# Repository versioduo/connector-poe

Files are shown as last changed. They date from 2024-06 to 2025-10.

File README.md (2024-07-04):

# connector-poe

⚡ V2 Link + Power Over Ethernet Mode B 

## Board

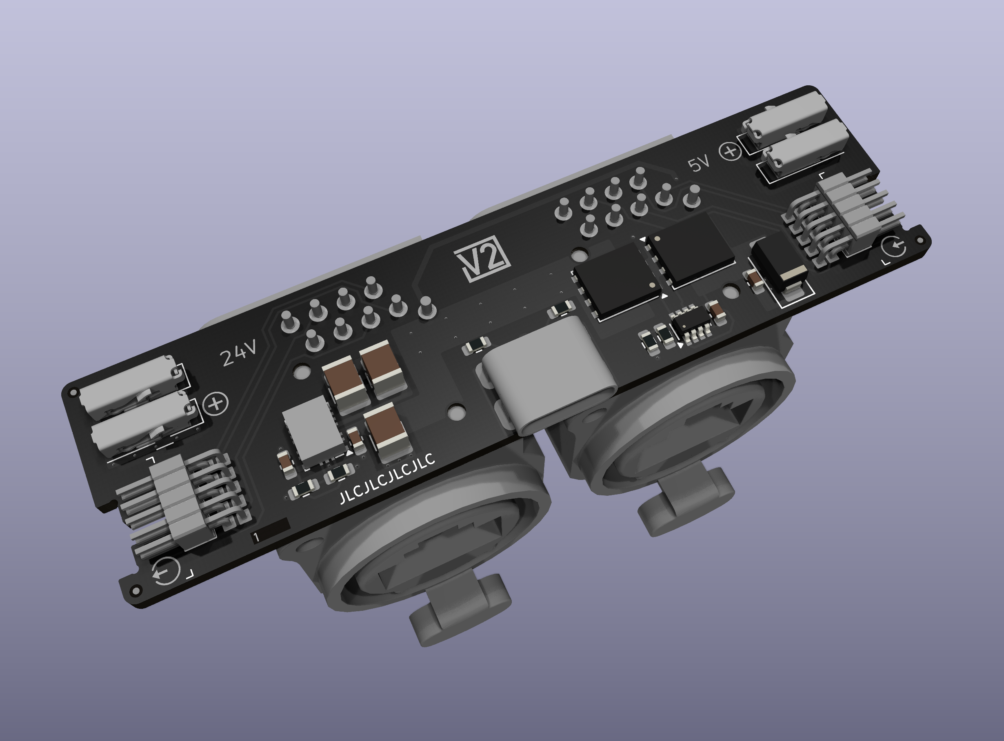
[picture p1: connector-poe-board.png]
board


## Schematic

[PDF](connector-poe.pdf)

## Bill Of Materials

[Interactive BOM](https://htmlpreview.github.io/?https://github.com/versioduo/connector-poe/main/connector-poe-bom.html)

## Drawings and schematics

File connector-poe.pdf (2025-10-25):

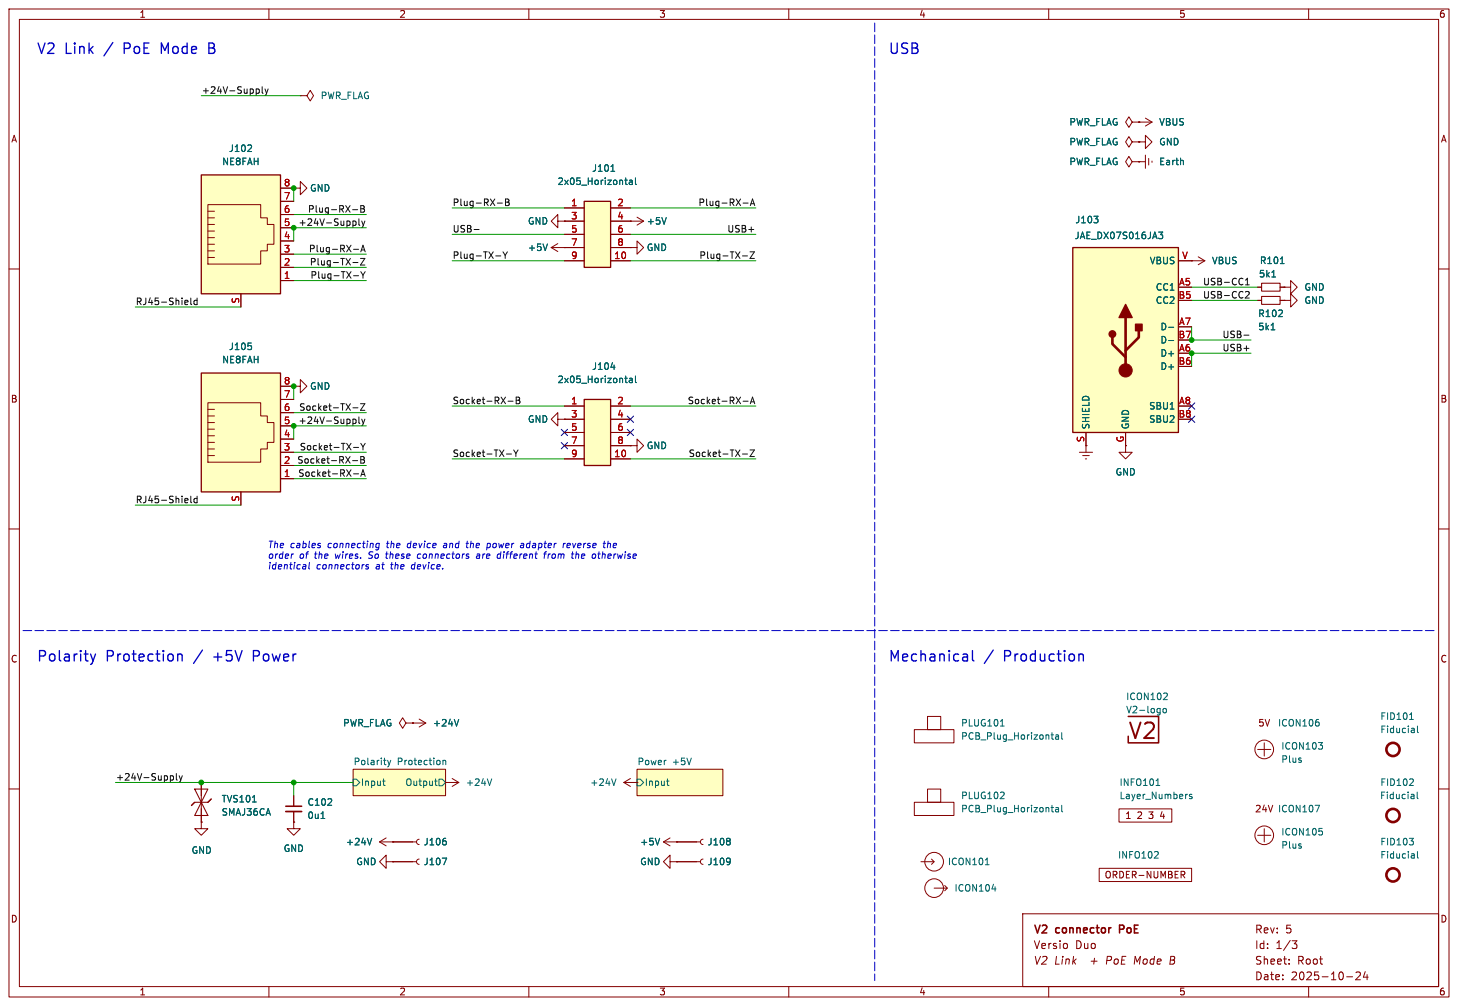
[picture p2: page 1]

Plug-TX-Z Socket-RX-A

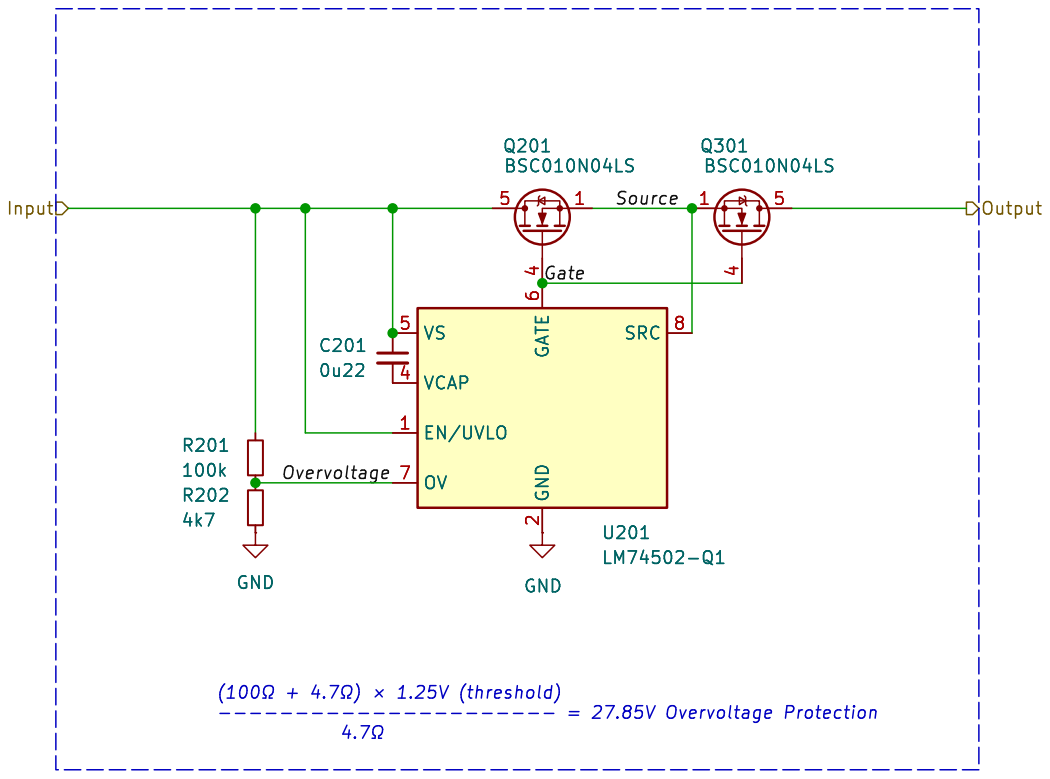
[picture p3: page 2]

þÿ(100©+ þÿ4.7©) þÿ×1.25V (threshold)

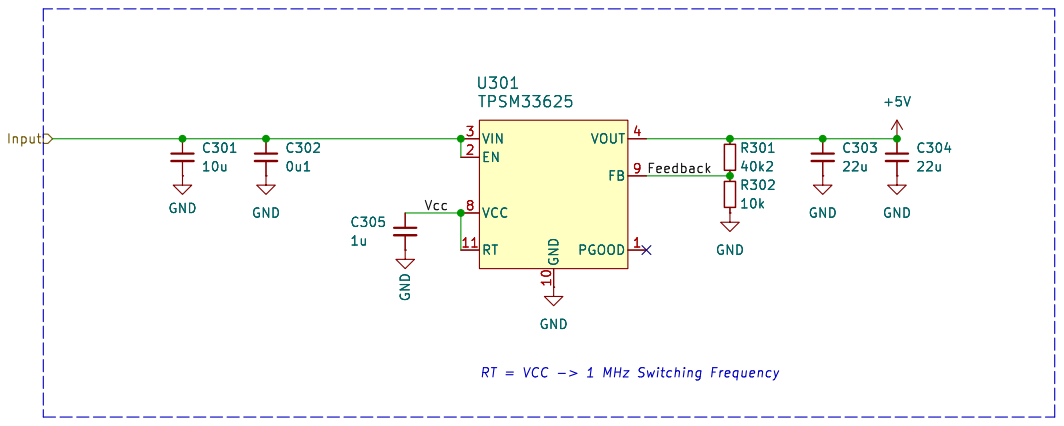
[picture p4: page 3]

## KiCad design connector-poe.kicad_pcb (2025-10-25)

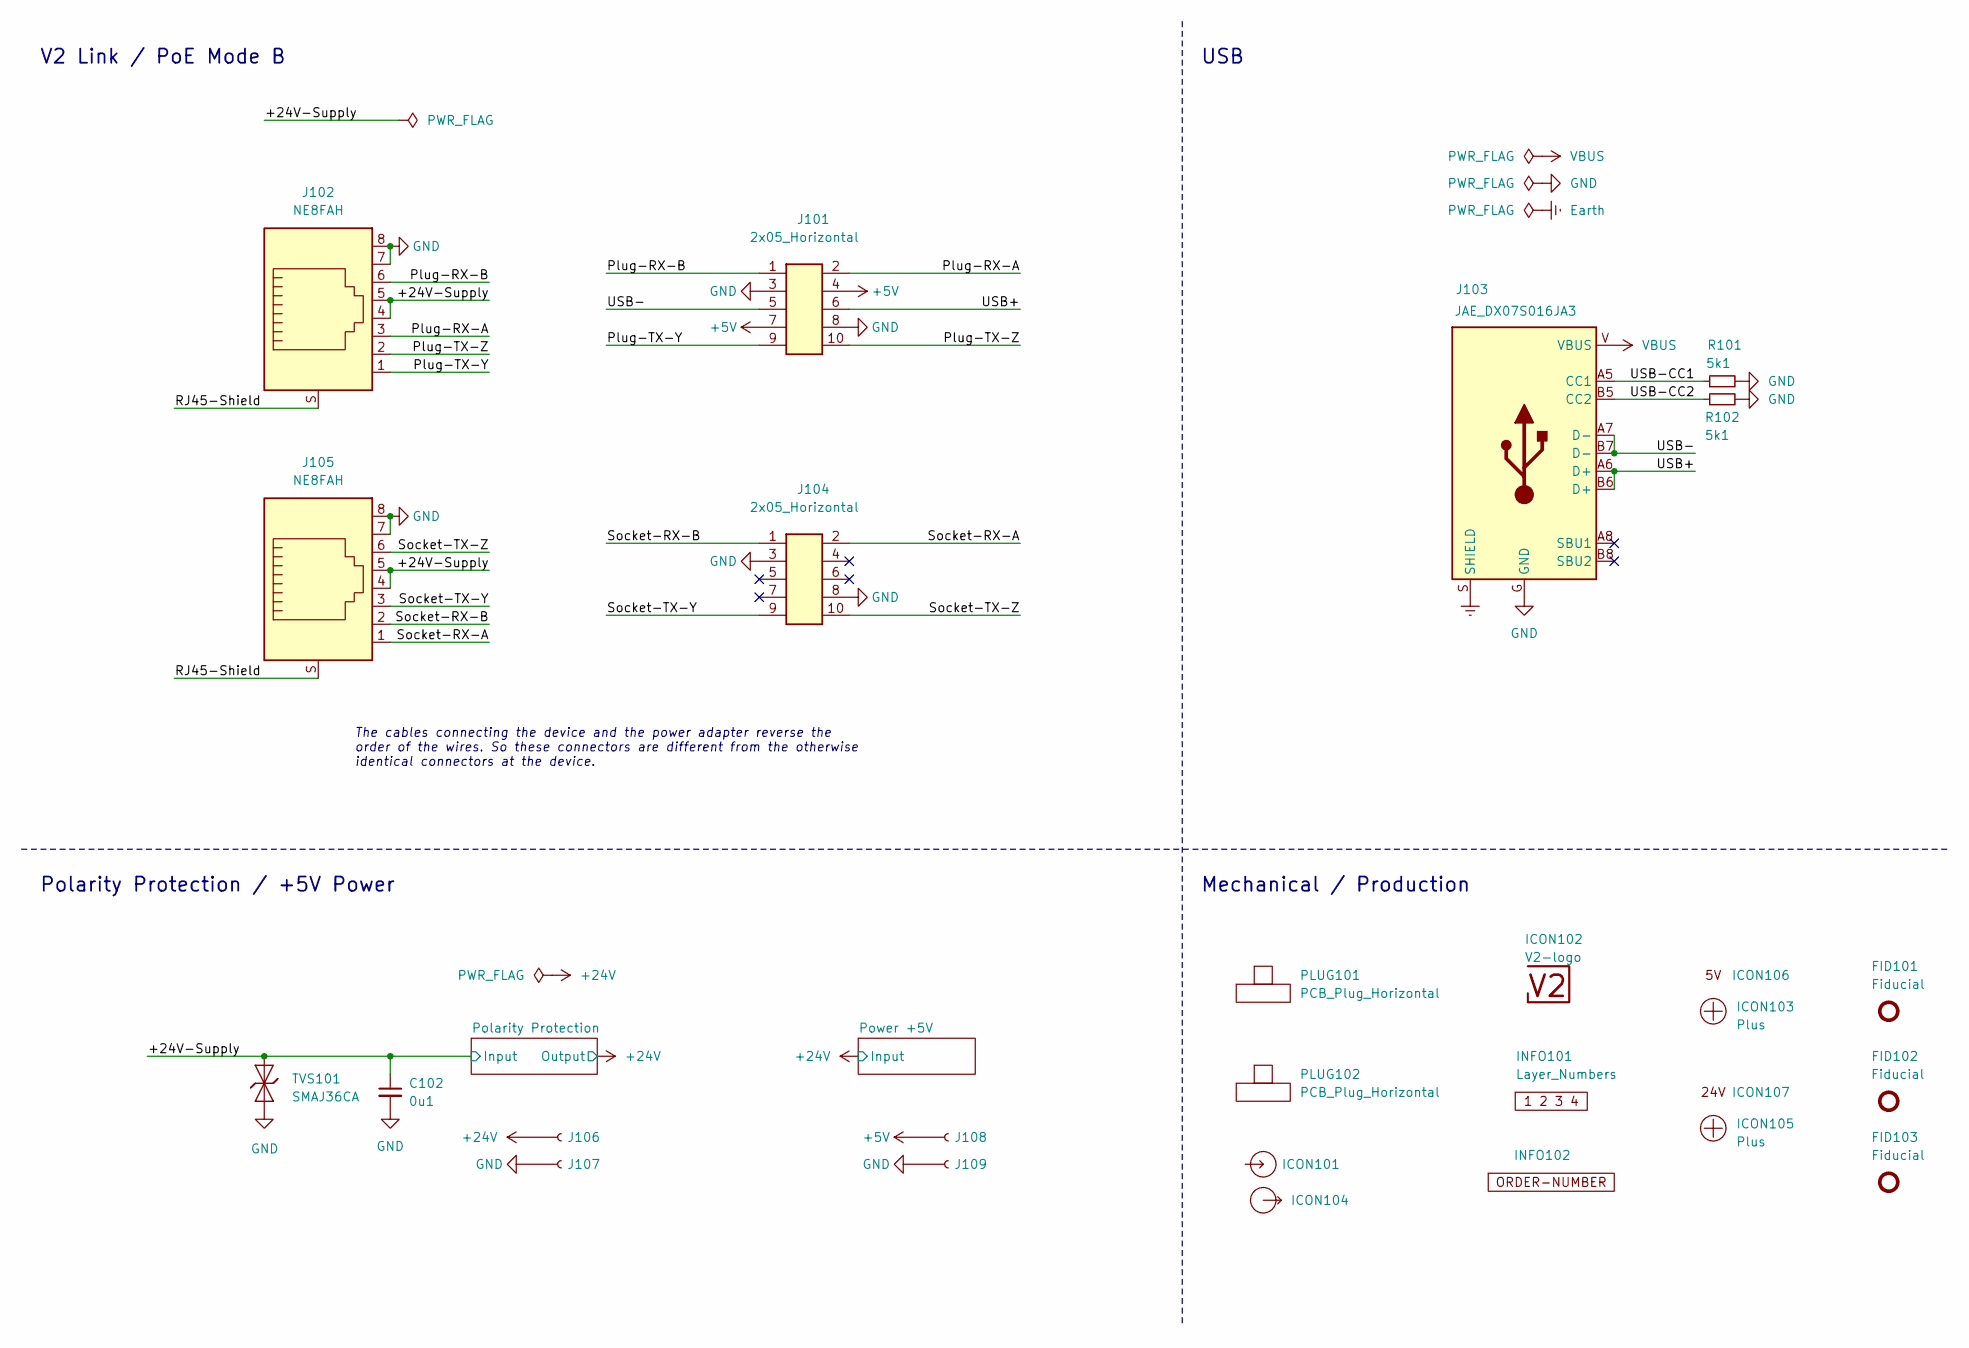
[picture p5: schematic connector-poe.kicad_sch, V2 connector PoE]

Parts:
C102: 0u1; C_0603_1608Metric
FID101, FID102, FID103: Fiducial; Fiducial_0.5mm_Mask1mm_Paste
ICON101: Arrow_In
ICON102: V2-logo; Logo_Small
ICON103, ICON105: Plus; Plus_Small
ICON104: Arrow_Out
ICON106: 5V
ICON107: 24V
INFO101: Layer_Numbers
INFO102: ORDER-NUMBER; Order_Number
J101, J104: 2x05_Horizontal; PinHeader_2x05_P1.27mm_Horizontal
J102, J105: NE8FAH
J103: JAE_DX07S016JA3
J106, J107, J108, J109: WAGO-2065; 2065-100
PLUG101, PLUG102: PCB_Plug_Horizontal
R101, R102: 5k1; R_0603_1608Metric
TVS101: SMAJ36CA; D_SMA

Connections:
+5V: J101.4, J101.7, J108.1; also elsewhere on the board
+24V: J106.1; also elsewhere on the board
/+24V-Supply: C102.1, J102.4, J102.5, J105.4, J105.5, TVS101.2 (A); also elsewhere on the board
/Plug-RX-A: J101.2, J102.3
/Plug-RX-B: J101.1, J102.6
/Plug-TX-Y: J101.9, J102.1
/Plug-TX-Z: J101.10, J102.2
/RJ45-Shield: J102.S, J105.S
/Socket-RX-A: J104.2, J105.1
/Socket-RX-B: J104.1, J105.2
/Socket-TX-Y: J104.9, J105.3
/Socket-TX-Z: J104.10, J105.6
/USB+: J101.6, J103.A6 (D+), J103.B6 (D+)
/USB-: J101.5, J103.A7 (D-), J103.B7 (D-)
/USB-CC1: J103.A5 (CC1), R101.1
/USB-CC2: J103.B5 (CC2), R102.1
Earth: J103.S (SHIELD)
GND: C102.2, J101.3, J101.8, J102.7, J102.8, J103.G (GND), J104.3, J104.8, J105.7, J105.8, J107.1, J109.1, R101.2, R102.2, TVS101.1 (K); also elsewhere on the board
VBUS: J103.V (VBUS)

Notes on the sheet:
Polarity Protection / +5V Power
Mechanical / Production
The cables connecting the device and the power adapter reverse the order of the wires. So these connectors are different from the otherwise identical connectors at the device.
USB
V2 Link / PoE Mode B

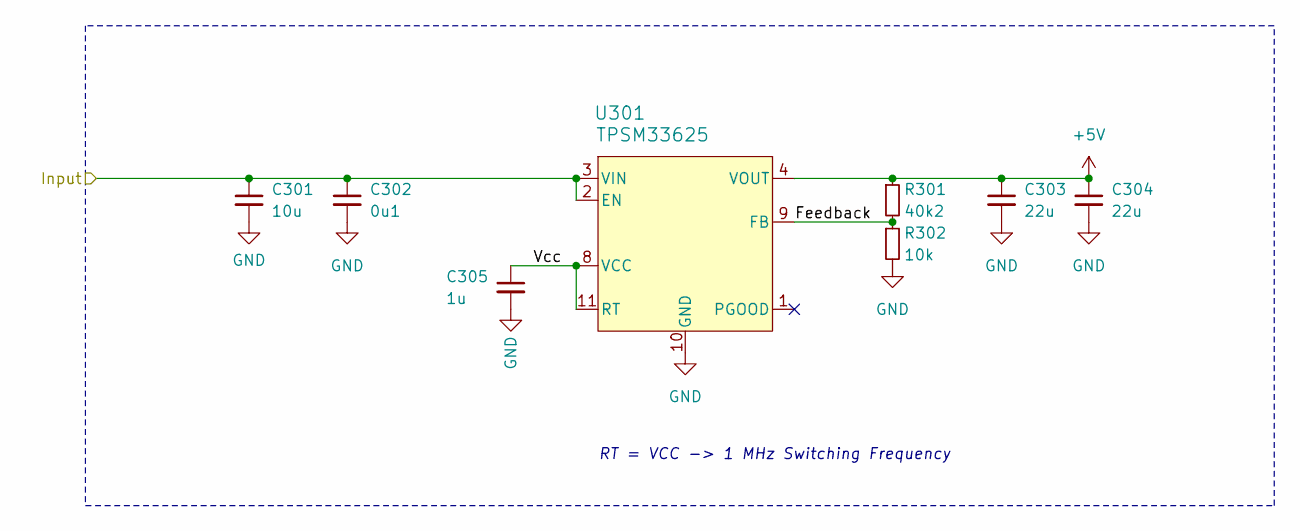
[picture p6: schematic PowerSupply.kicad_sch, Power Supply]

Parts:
C301: 10u; C_1210_3225Metric
C302: 0u1; C_0603_1608Metric
C303, C304: 22u; C_1210_3225Metric
C305: 1u; C_0603_1608Metric
R301: 40k2; R_0603_1608Metric
R302: 10k; R_0603_1608Metric
U301: TPSM33625

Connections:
+5V: C303.1, C304.1, R301.1, U301.4 (VOUT); also elsewhere on the board
+24V: C301.1, C302.1, U301.2 (EN), U301.3 (VIN); also elsewhere on the board
/Power +5V/Feedback: R301.2, R302.1, U301.9 (FB)
/Power +5V/Vcc: C305.1, U301.8 (VCC), U301.11 (RT)
GND: C301.2, C302.2, C303.2, C304.2, C305.2, R302.2, U301.10 (GND); also elsewhere on the board

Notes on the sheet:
RT = VCC -> 1 MHz Switching Frequency

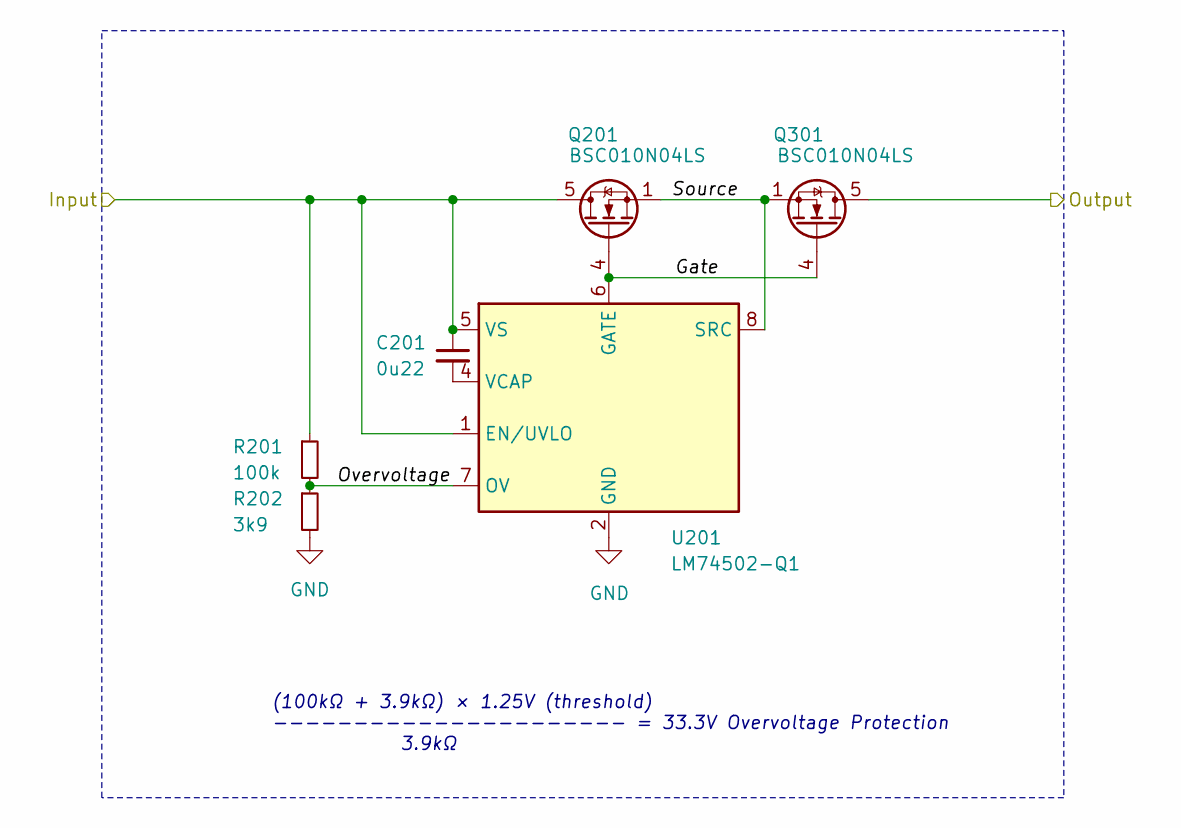
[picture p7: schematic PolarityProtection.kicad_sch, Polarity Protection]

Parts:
C201: 0u22; C_0603_1608Metric
Q201, Q301: BSC010N04LS; TDSON-8-FL
R201: 100k; R_0603_1608Metric
R202: 3k9; R_0603_1608Metric
U201: LM74502-Q1; SOT-23-8

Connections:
+24V: Q301.5 (D); also elsewhere on the board
/+24V-Supply: C201.1, Q201.5 (D), R201.1, U201.1 (EN/UVLO), U201.5 (VS); also elsewhere on the board
/Polarity Protection/Gate: Q201.4 (G), Q301.4 (G), U201.6 (GATE)
/Polarity Protection/Overvoltage: R201.2, R202.1, U201.7 (OV)
/Polarity Protection/Source: Q201.1 (S), Q301.1 (S), U201.8 (SRC)
GND: R202.2, U201.2 (GND); also elsewhere on the board
unnamed: C201.2, U201.4 (VCAP)

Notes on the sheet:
(100kΩ + 3.9kΩ) × 1.25V (threshold) ---------------------- = 33.3V Overvoltage Protection 3.9kΩ

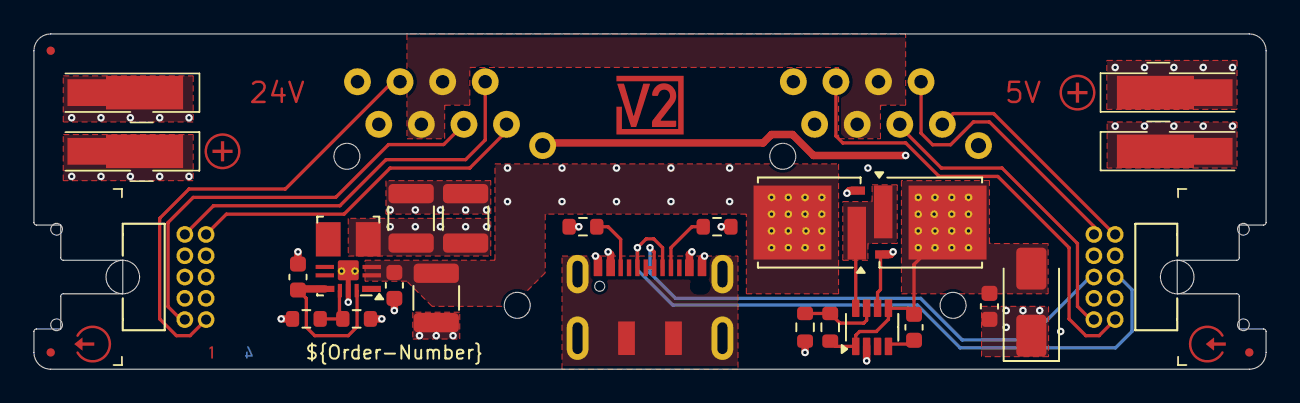
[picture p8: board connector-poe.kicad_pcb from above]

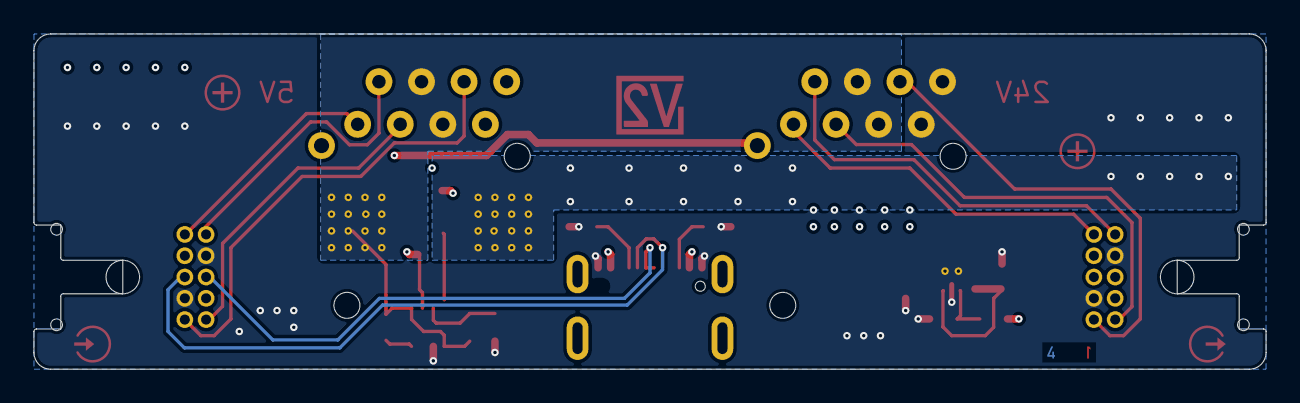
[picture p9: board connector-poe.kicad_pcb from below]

Board: 4 copper layers, 73.5 x 20.0 mm, 41 parts (2 on the bottom side), 23 nets.

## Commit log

2024-03-28 Update to Kicad 8
    [PolarityProtection.kicad_sch, PowerSupply.kicad_sch, power-rj45.kicad_pcb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]
2024-03-28 Update DCDC
    [PolarityProtection.kicad_sch, PowerSupply.kicad_sch, power-rj45.kicad_pcb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]
2024-06-20 Update icons
    [PolarityProtection.kicad_sch, PowerSupply.kicad_sch, power-rj45.kicad_pcb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]
2024-06-20 Replace icons
    [power-rj45.kicad_pcb, power-rj45.kicad_sch]
2024-07-04 Rename to connector-poe
    [connector-poe.kicad_pcb, connector-poe.kicad_sch]
2025-10-25 Back-to-back Mosfet
    [PolarityProtection.kicad_sch, PowerSupply.kicad_sch, connector-poe.kicad_pcb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]
